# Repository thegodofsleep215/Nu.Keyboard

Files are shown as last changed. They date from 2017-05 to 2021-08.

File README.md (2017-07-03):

# Overview
The purpose of this repo is to document and provide my experience in making a mechanical keyboard. Why I made my own instead of using someone elses. The layout of the keys, the parts I used. How to wire a keyboard. And last but not least, how to program the firmware.

1. [Motivations](Motivation/README.md)
2. [Keyboard Layout](Layout/README.md)
3. [Parts](Parts/README.md)
4. [Wiring](Wiring/README.md)
5. [Firmware Programming](Firmware/README.md)

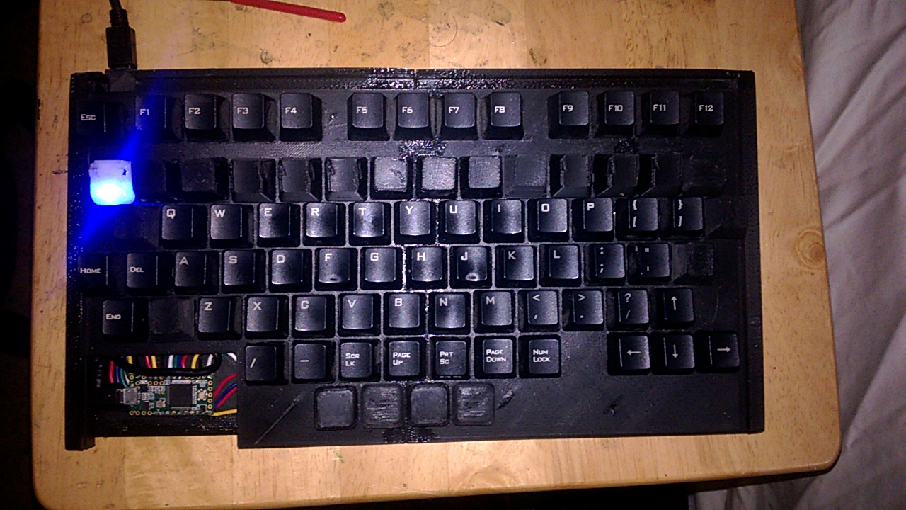
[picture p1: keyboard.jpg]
Mostly Finished Keyboard


# References
Some of the reference I used.
## General
* http://pcbheaven.com/wikipages/How_Key_Matrices_Works/
* http://blog.komar.be/how-to-make-a-keyboard-the-matrix/
## Keyboard Layout
* https://geekhack.org/index.php?topic=47744.0
* https://upload.wikimedia.org/wikipedia/commons/1/10/Key_offset_in_alphanumeric_section_of_a_keyboard_according_to_DIN_2137-2--2012-06.svg
## Wiring
* https://deskthority.net/workshop-f7/brownfox-step-by-step-t6050.html
## Programming
* https://github.com/tmk/tmk_keyboard

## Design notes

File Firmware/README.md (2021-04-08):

# Firmware
## Disclaimer 
There may be more efficient ways of solving this problem. This worked for me to the point where I can't tell the difference between it and a manufactured keyboard.

## Looping
The program runs in a loop. Executing what I am assuming is as fast as the controller can go. On every loop your program will need to read which rows/columns have been pressed or depressed and then send the information on to the computer.

## I/O Types
It is important to understand the I/O types for pins. Since you wire a keyboard in a matrix and read rows and columns. Your firmware will need to switch pins constantly to ensure it is reading the correct value. The two input types are INPUT_PULLDOWN, and INPUT_PULLUP. The first is LOW when the switch is open and HIGH when the switch is closed. The other is the opposite. You'll also need to set the output of your other pin correctly. When using INPUT_PULLDOWN set your other pin mode to OUTPUT and write HIGH to it. When reading from an INPUT_PULLUP pin you'll need to set the other pin's mode to OUTPUT_OPENDRAIN and write LOW to it.

## Selecting Row and Columns 
This program tests each button individually. It iterates over each row for each column. It selects a column (minding I/O types talked about above) and reads from it. It then does the same for every row. Each time a row is read the program tests to see is a key has been pressed or depressed, saving the state to a buffer. After all columns and rows have been read key modifiers are set (ctrl, alt, gui...), LEDs are toggled, and the information is sent along to the computer.

Some simplified pseudo-code:
* Select Column
  * Read Column
  * Deselect Column
  * Select Row
    * Read Row
    * Toggle Press/Depress as needed
    * Deselct Row
* Set Modifiers
* Toggle LEDs
* Send to Computer

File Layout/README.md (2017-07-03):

# Layout
## Mostly Standard
I'm not interested anything drastic like dvorak. The main section of the keybaord was to remain mostly intact. The section with the arrows keys and over would be lopped off and consolidated with the main keyboard.
## The Spacebar
As the main driver was to add more buttons for the thumb the spacebar would only be one [unit](https://deskthority.net/wiki/Unit). In it's place from left to right would be the windows key, tab, spacebar, alt, backspace, delete, and context menu. This row was going to be aligened with the one above it.
## Another Row
It seemed reasonable to add another row below the space bar. This is a four button row offset half a unit from the spacebar row. From left to right it would have page up, shift, control, page down.
## Arrow Keys
I like using the arrow key for some things. I moved that left under the enter key.
## Other Modifications
Since some of the keys haved moved under the thumb. I filled in some missing keys around. Tilde got moved to where Tab was, caps lock moved to where tilde was, backslash got moved to where caps lock was, insert home and end went on the left side filling out where shift and part of caps lock were. Last I put print sreen where backspace was and Pause/Break where backslash was. Believe it or not I use Pause/Break.

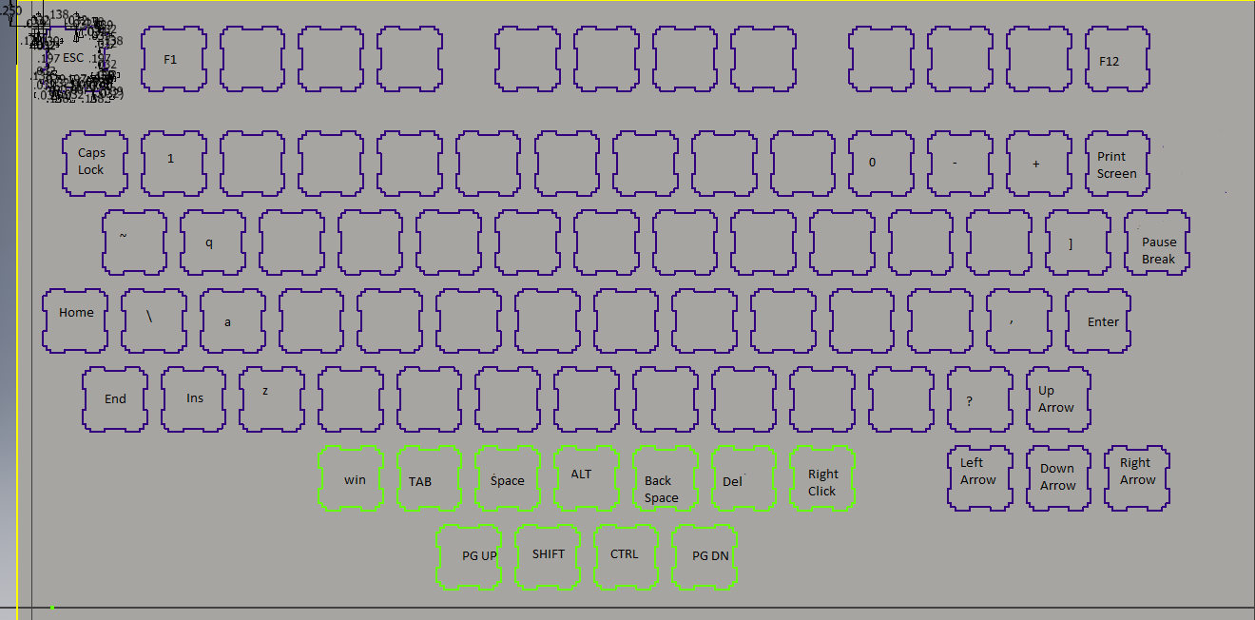
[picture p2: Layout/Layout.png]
Rough Layout of the kaycap placment.


# Key Caps
## Parametric Key Caps and Unconventional Key Locations
I primarily use a 'DAS Keyboard' which has parametric keycaps. I though I'd play with this a bit since I put some keys in unconventional locations. My new row has a very short key cap new row to make it easier to avoid fat finger it. I'd also make caps lock and print screen shorter than the keys around them for the same reason. The spacebar row also got keys angled for the number row, since I didn't want my fingers to hit them as easily.

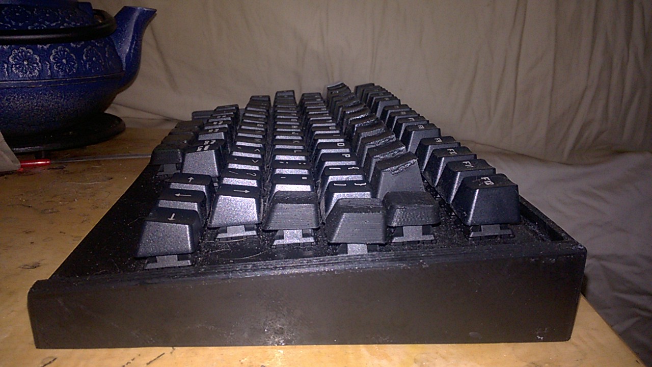
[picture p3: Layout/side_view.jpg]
Side view of key caps.


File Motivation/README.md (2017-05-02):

# Motivation
## Left Handed Gaming Options
As a lefty I use IJLK instead of WASD for gaming. There are more buttons for the pinky on right side of the keyboard. As I used them more and more I started to get a strain injury in my forearm. Instead of doing the sensible thing of remapping keys to use my pinky less. I stared at the space bar in disgust. I use my thumb a lot when I use a controller, why not when on a keyboard? The original idea was not to make a keyboard, but instead a gaming a device that had enough keys for one had to reach without moving. Somthing like the 'Razer Nostromo,' with no stick and more buttons.
## Programmer
As I started to lay out the design it occurred to me it would be simple enough to mirror what I what I had to make a keyboard. I'd only put the keys I used and lop off the number pad to make it nice and compact. Since I'm going for a "don't move your hand" approach for gaming why not for programming/typing as well. I use VIM or a VIM plug in for most all work, but that doesn't always exist. Since I'll be using my thumb more for gaming, why not when typing as well?
## Learning How
After I had a layout I liked I started to search around for tutorials. That's when I ran across the 'ErgoDox.' An ergnomical keybaord that had the same why-is-the-space-bar-so-big inspiration. As I already had the itch to do it myself I decided it would be best just to make my own. I've not really played with Arduinos and this seems like a great excuse. The project is both useful and educational!
## 3D Printer
I own a 3D printer. This helps justify my purchase...as if I needed to...
## This Document
It was not on my radar to create this document when I started. I wanted to make every aspect of my keyboard; key layout, case, wire it, and program it. There is a lot of good info on how to do the first three, but I was having trouble finding a good guide on how to program a keyboard. Everything I found pointed to, [tmk_keyboard](https://github.com/tmk/tmk_keyboard). A great resource, and if you don't want to write your own firmware I suggest using it. It was not for me though. So I was left to bashing my head and reading forums about teensyduino. So after all I went through I thought I'd write something for the next guy or gal. So if you are looking write your own keyboard firmware, then this doc was made for you. I hope it helps.

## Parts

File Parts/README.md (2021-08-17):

# Parts
<table>
  <tr><th>Type</th><th>Part Used</th><th>Quantity</th></tr>
  <tr><td>Switch</td><td>Cherry MX Brown</td><td>82</td></tr>
  <tr><td>Diodes</td><td>1N4148</td><td>82</td></tr>
  <tr><td>LED</td><td>Blue 3MM LED</td><td>1</td></tr>
  <tr><td>Resistor</td><td>Came with LED</td><td>1</td></tr>
  <tr><td>KeyCaps</td><td>Donor keys from DAS Keyboard, 3D prints from http://www.thingiverse.com/thing:468651</td><td>82</td></tr>
  <tr><td>Controller</td><td>Teensyduino 3.2</td><td>1</td></tr>
</table>

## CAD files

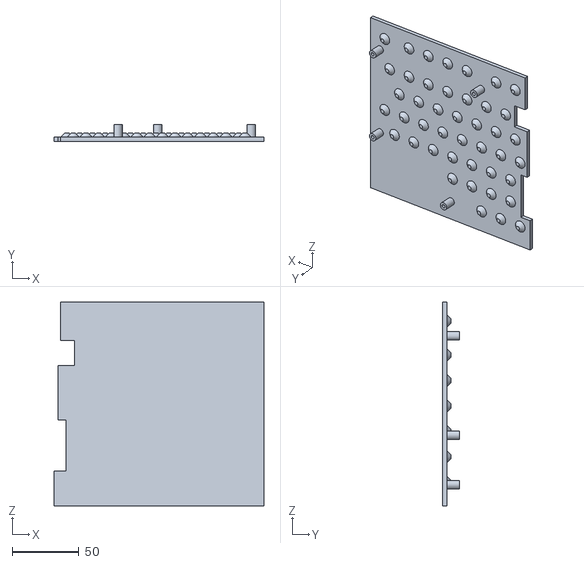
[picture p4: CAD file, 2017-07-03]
Parts/3D Models/bottom_left.stl
157.2 x 12.7 x 152.4

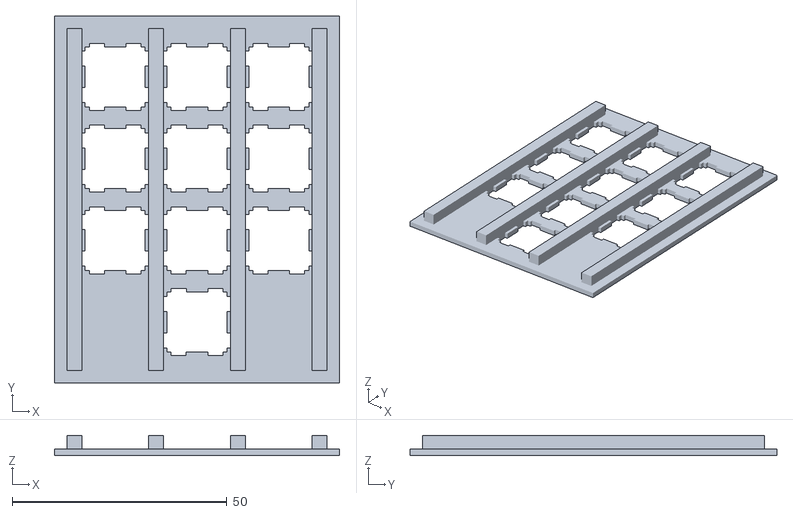
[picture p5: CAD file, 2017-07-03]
Parts/3D Models/number_pad_mount_plate.stl
66.4 x 85.4 x 4.67

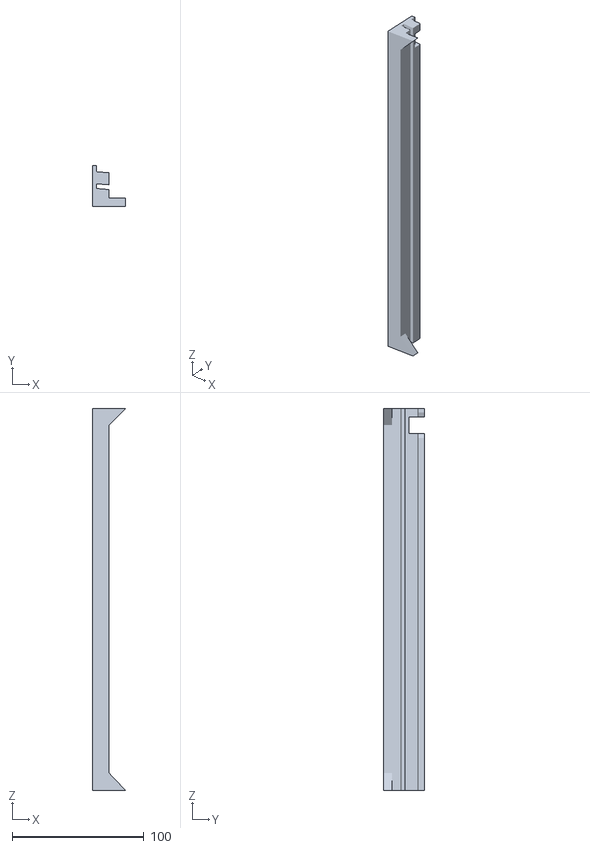
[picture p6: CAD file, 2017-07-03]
Parts/3D Models/back.stl
25.4 x 31.0 x 290.2

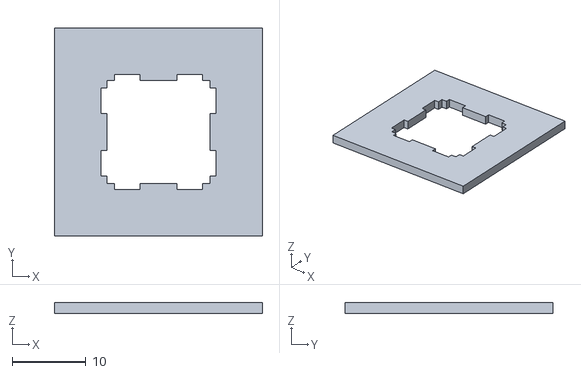
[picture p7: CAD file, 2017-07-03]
Parts/3D Models/demo_mount_plate.stl
28.3 x 28.3 x 1.50

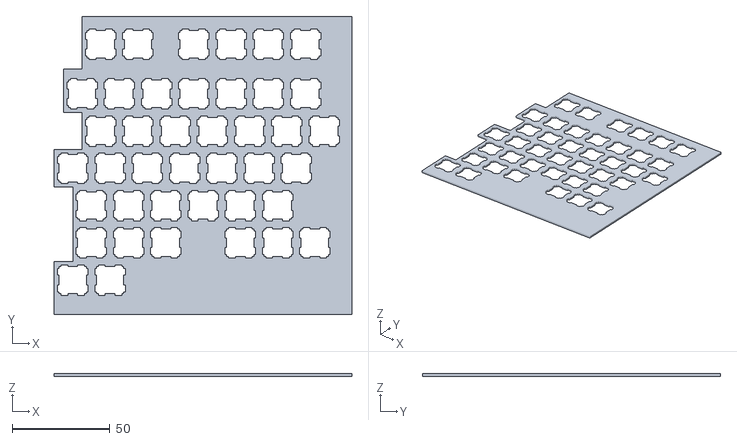
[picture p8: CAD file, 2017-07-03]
Parts/3D Models/switch_mount_plate_right.stl
152.3 x 152.4 x 1.50

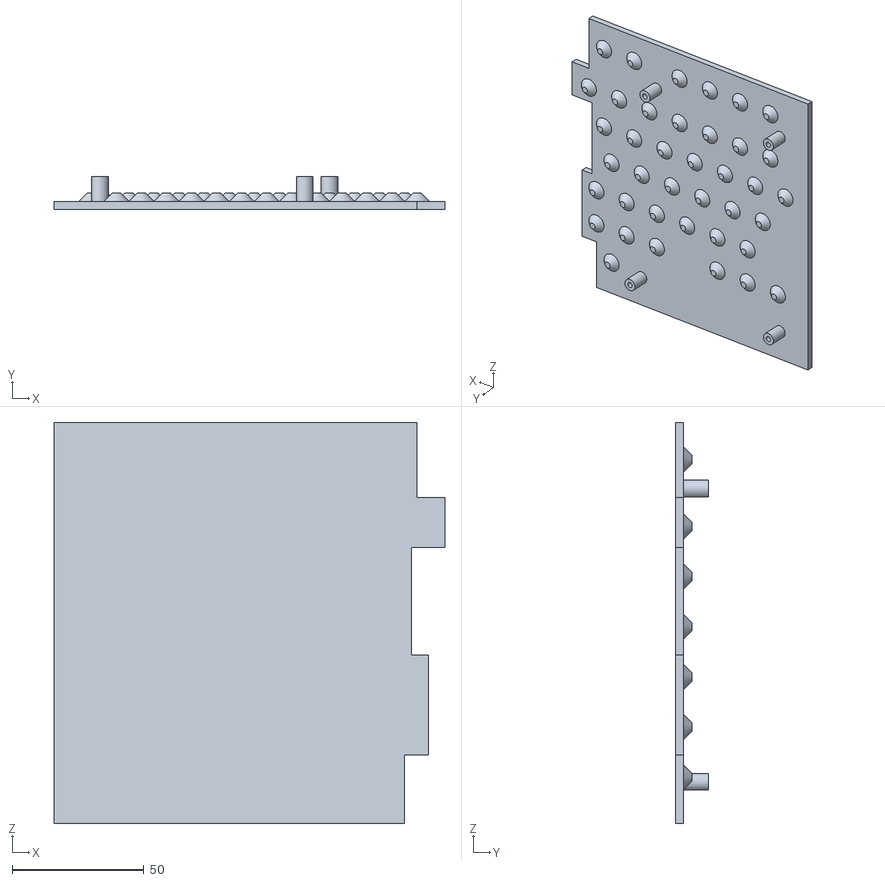
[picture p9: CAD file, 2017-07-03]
Parts/3D Models/bottom_right.stl
148.5 x 12.7 x 152.4

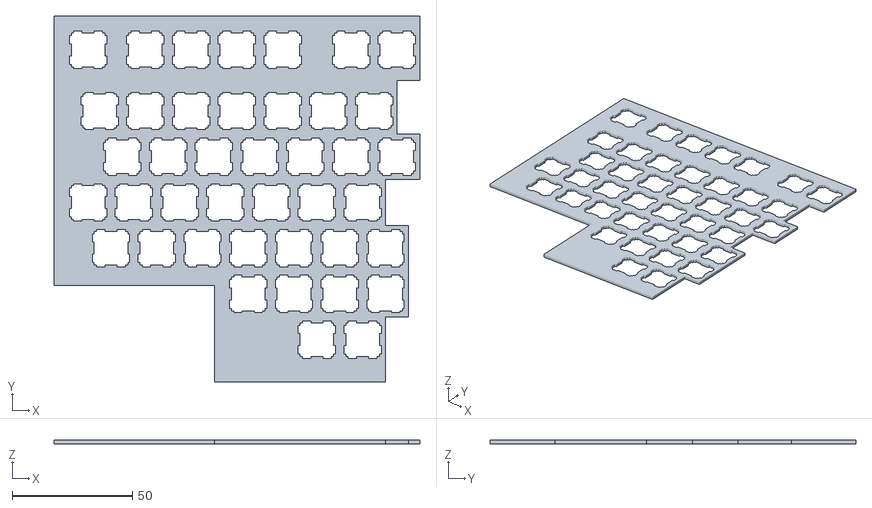
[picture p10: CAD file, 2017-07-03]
Parts/3D Models/switch_mount_plate_left.stl
152.2 x 152.4 x 1.50

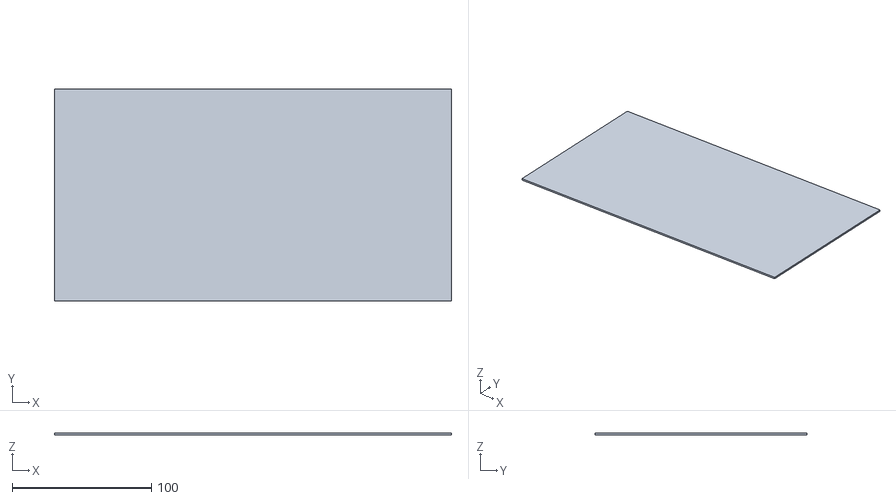
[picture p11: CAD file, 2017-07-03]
Parts/3D Models/switch_mount_plate.stl
285.5 x 152.4 x 1.50

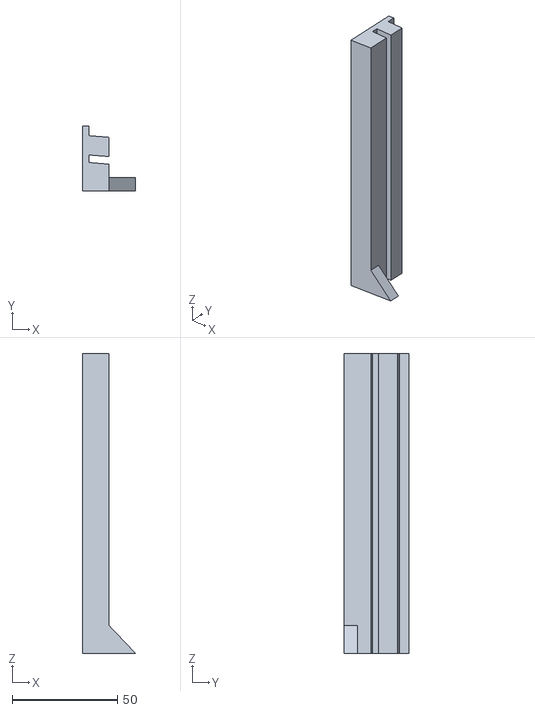
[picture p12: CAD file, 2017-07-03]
Parts/3D Models/back_right.stl
25.4 x 31.0 x 142.6

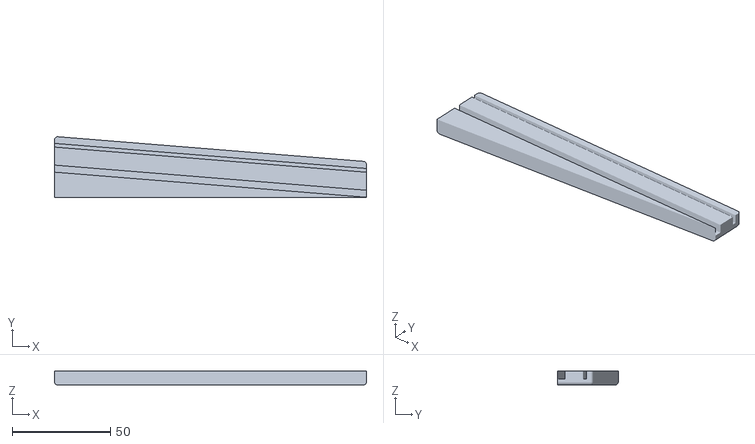
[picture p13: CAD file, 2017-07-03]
Parts/3D Models/wall.stl
158.8 x 30.8 x 7.14

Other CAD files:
Parts/3D Models/back_left.stl

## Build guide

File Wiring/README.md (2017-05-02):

# Wiring
I'm not going to go very indepth with this step. I've included the reference I used to learn this. They are very good and I don't see the point in duplicating that info. 
The bottom two rows were wired as a single row since they are 13 keys in total.

## Tips
* I used my diodes to wire the rows, wires for the columns. It doesn't matter, it just made it easier.
* Make sure all of your diodes go in the same direction.
* I found it easier to run the diodes/wires the length of the row/column and cut it, then soder a wire from a convenient location on the row/column and run the cable to the controller.
* If you want your rows and columns to line up to pin numbers in a left-to-right top-to-bottom way, remember that you are sodering something that is upside down.
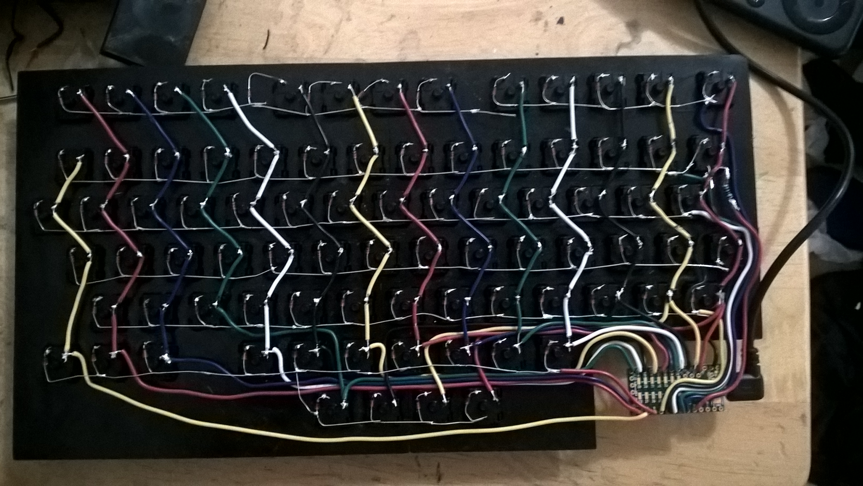
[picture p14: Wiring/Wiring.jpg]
Final Wiring Done


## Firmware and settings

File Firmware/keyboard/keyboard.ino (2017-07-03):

// Time to wait for key debounce
#define DEBOUNCE 1

// Number of columns on the keyboard matrix (highest if columns are not equal)
#define NUM_OF_COLS 14
// Number of rows on the keyboard matrix (highest if rows are not equal)
#define NUM_OF_ROWS 6

// Pin wired to caps lock LED. -1 if no LED is present.
#define CAPS_LOCK_PIN 3
// Pin wired to scroll lock LED. -1 if no LED is present.
#define SCROLL_LOCK_PIN -1
// Pin wired to num lock LED. -1 if no LED is present.
#define NUM_LOCK_PIN -1

// Pin numbers for columns in order they are wired with respect to keyMap. FYI: Column pins are INPUT_PULLDOWN
int cols[NUM_OF_COLS] =  {23,22,21,20,19,18,17,16,15,14,13,12,11,10};
// Pin numbers for rows in order they are wired with respect to keyMap. FYI: Row pins are INPUT_PULLUP
int rows[NUM_OF_ROWS] = {4,5,6,7,8,9};

// The order that buttons are wired. FYI, keyMap[0][0] will activated if pins at cols[0], rows[0] are on.
int keyMap[NUM_OF_ROWS][NUM_OF_COLS] = 
{
  { KEY_ESC,       KEY_F1,        KEY_F2, KEY_F3, KEY_F4, KEY_F5, KEY_F6, KEY_F7, KEY_F8, KEY_F9,    KEY_F10,    KEY_F11,        KEY_F12,         0 },
  { KEY_CAPS_LOCK, KEY_1,         KEY_2,  KEY_3,  KEY_4,  KEY_5,  KEY_6,  KEY_7,  KEY_8,  KEY_9,     KEY_0,      KEY_MINUS,      KEY_EQUAL,       KEY_PRINTSCREEN },
  { KEY_TILDE,     KEY_Q,         KEY_W,  KEY_E,  KEY_R,  KEY_T,  KEY_Y,  KEY_U,  KEY_I,  KEY_O,     KEY_P,      KEY_LEFT_BRACE, KEY_RIGHT_BRACE, KEY_PAUSE},
  { KEY_HOME,      KEY_BACKSLASH, KEY_A,  KEY_S,  KEY_D,  KEY_F,  KEY_G,  KEY_H,  KEY_J,  KEY_K,     KEY_L,      KEY_SEMICOLON,  KEY_QUOTE,       KEY_ENTER },
  { KEY_END,       KEY_INSERT,    KEY_Z,  KEY_X,  KEY_C,  KEY_V,  KEY_B,  KEY_N,  KEY_M,  KEY_COMMA, KEY_PERIOD, KEY_SLASH,      KEY_UP,          0 },
  { KEY_PAGE_UP, MODIFIERKEY_SHIFT, MODIFIERKEY_CTRL, MODIFIERKEY_GUI, KEY_TAB, KEY_SPACE, MODIFIERKEY_ALT, KEY_BACKSPACE, KEY_DELETE, 101, KEY_PAGE_DOWN, KEY_LEFT, KEY_DOWN, KEY_RIGHT }
};


// Blow this line is "unconfigurable"


// 2D array to keep track of which keys are pressed
int** keyState;

// Storage for which key is pressed in which "slot"
int keys[6] {0, 0, 0, 0, 0, 0};

// Storage for pressed modifiers.
int modifiers[4] {0, 0, 0, 0};
// Indexs for modifier keys in modifiers buffer
#define SHIFT 0
#define CTRL 1
#define ALT 2
#define GUI 3

// LED numbers for usb_keyboard.h
#define USB_LED_NUM_LOCK 0
#define USB_LED_CAPS_LOCK 1
#define USB_LED_SCROLL_LOCK 2
#define USB_LED_COMPOSE 3
#define USB_LED_KANA 4

void setup() {
  // Turn on LEDs for output
  if(CAPS_LOCK_PIN >= 0)
  {
    pinMode(CAPS_LOCK_PIN, OUTPUT);
  }
  if(SCROLL_LOCK_PIN >= 0)
  {
    pinMode(SCROLL_LOCK_PIN, OUTPUT);
  }
  if(NUM_LOCK_PIN >= 0)
  {
    pinMode(NUM_LOCK_PIN, OUTPUT);
  }


  // Create and initialize keyState off rows by columns.
  keyState = (int**)malloc(NUM_OF_ROWS * sizeof(int*)); 
  for (int i = 0; i < NUM_OF_ROWS; i++) {
       keyState[i] = (int *)malloc(NUM_OF_COLS * sizeof(int));
  }
  for (int i = 0; i < NUM_OF_ROWS; i++) {
    for(int c = 0; c < NUM_OF_COLS; c++)
    {
      keyState[i][c] = LOW;
    }
  }
  
}

// Read the column, HIGH if on LOW of off.
int ReadColumn(int index)
{
  for(int i = 0; i < NUM_OF_ROWS; i++)
  {
    pinMode(rows[i], OUTPUT);
    digitalWrite(rows[i], HIGH);
  }
  pinMode(cols[index], INPUT_PULLDOWN);
  delay(DEBOUNCE);
  return digitalRead(cols[index]);
}

// Checks for an open button to send
int CheckForButton()
{
    for(int i = 0; i < 6; i++){
      if(keys[i] == 0) return i;
    }
    return -1;
}

// Sets the modifier buffer if a modifier key was pressed.
bool SetModifier(int b)
{
  if(b == MODIFIERKEY_SHIFT)
  {
    modifiers[SHIFT] = MODIFIERKEY_SHIFT;
    return true;
  }
  else if (b == MODIFIERKEY_CTRL)
  {
    modifiers[CTRL] = MODIFIERKEY_CTRL;
    return true;
  }
  else if (b == MODIFIERKEY_ALT)
  {
    modifiers[ALT] = MODIFIERKEY_ALT;
    return true;
  }
  else if (b == MODIFIERKEY_GUI)
  {
    modifiers[GUI] = MODIFIERKEY_GUI;
    return true;
  }
  return false;
}

// Unsets a modifer button from the buffer.
bool UnsetModifier(int b)
{
    if(b == MODIFIERKEY_SHIFT)
  {
    modifiers[SHIFT] = 0;
    return true;
  }
  else if (b == MODIFIERKEY_CTRL)
  {
    modifiers[CTRL] = 0;
    return true;
  }
  else if (b == MODIFIERKEY_ALT)
  {
    modifiers[ALT] = 0;
    return true;
  }
  else if (b == MODIFIERKEY_GUI)
  {
    modifiers[GUI] = 0;
    return true;
  }
  return false;
}

// Ors all modifiers and sets them on the keyboard.
void SendModifiers()
{
  int m = 0;
  for(int i = 0; i < 4; i++)
  {
    m |= modifiers[i];
  }
  Keyboard.set_modifier(m);
}

// Checks to see if a button is pressed in the buffer
int CheckForPressedButton(int b)
{
  for(int i = 0; i < 6; i++){
    if(keys[i] == b)
    { 
      return i;
    }
  }
  return -1;
}

// Sets the key based off of the position in the buffer
void PressButton(int index, int b){
  keys[index] = b;
    switch(index + 1){
      case 1:
        Keyboard.set_key1(b);
        break;
      case 2:
        Keyboard.set_key2(b);
        break;
      case 3:
        Keyboard.set_key3(b);
        break;
      case 4:
        Keyboard.set_key4(b);
        break;
      case 5:
        Keyboard.set_key5(b);
        break;
      case 6:
        Keyboard.set_key6(b);
        break;
    
  }
}

// Unpresses a key based off of its position in the buffer
void DepressButton(int index){
  keys[index] = 0;
  switch(index + 1){
    case 1:
      Keyboard.set_key1(0);
      break;
    case 2:
      Keyboard.set_key2(0);
      break;
    case 3:
      Keyboard.set_key3(0);
      break;
    case 4:
      Keyboard.set_key4(0);
      break;
    case 5:
      Keyboard.set_key5(0);
      break;
    case 6:
      Keyboard.set_key6(0);
      break;
  }
}

// Checks to see if LED lights should be on or off.
void ToggleLeds()
{
  if(CAPS_LOCK_PIN >= 0 && keyboard_leds & (1<<USB_LED_CAPS_LOCK))
  {
    digitalWrite(CAPS_LOCK_PIN, HIGH);
  }
  else
  {
    digitalWrite(CAPS_LOCK_PIN, LOW);
  }
  
  if(NUM_LOCK_PIN >= 0 && keyboard_leds & (1<<USB_LED_NUM_LOCK))
  {
    digitalWrite(NUM_LOCK_PIN, HIGH);
  }
  else
  {
    digitalWrite(NUM_LOCK_PIN, LOW);
  }
  
  if(SCROLL_LOCK_PIN >= 0 && keyboard_leds & (1<<USB_LED_NUM_LOCK))
  {
    digitalWrite(SCROLL_LOCK_PIN, HIGH);
  }
  else
  {
    digitalWrite(SCROLL_LOCK_PIN, LOW);
  }
}

// Test a key to see if it was just depressed.
void TryKeyDepressed(int r, int c, int readRow)
{
  if(readRow == HIGH && keyState[r][c] == HIGH)
  {
    keyState[r][c] = LOW;
    if(!UnsetModifier(keyMap[r][c]))
    {
      int b = CheckForPressedButton(keyMap[r][c]);
      if(b >= 0)
      {
        //digitalWrite(ledPin,LOW); 
        DepressButton(b);
      }
    }
  }
}

// Test a key to see if it was just pressed.
bool TryKeyPressed(int r, int c, int readRow)
{
  if(readRow == LOW && keyState[r][c] == LOW)
  {
    keyState[r][c] = HIGH;
    if(!SetModifier(keyMap[r][c]))
    {
      int b = CheckForButton();
      if(b >= 0)
      {
        //digitalWrite(ledPin,HIGH); 
        PressButton(b, keyMap[r][c]);
      }
    }
    return true;
  }
  return false;
}

void loop() {
  for(int c = 0; c < NUM_OF_COLS; c++)
  {
    int readC = ReadColumn(c);

    // Turn column read off
    pinMode(cols[c], OUTPUT_OPENDRAIN);
    digitalWrite(cols[c], LOW);
    delay(DEBOUNCE);
    
    for(int r = 0; r < NUM_OF_ROWS; r++)
    {
      // Turn on row for reading
      pinMode(rows[r], INPUT_PULLUP);
      
      int readRow = digitalRead(rows[r]);
      if(readC == HIGH)
      {
        if(!TryKeyPressed(r, c, readRow))
        {
          TryKeyDepressed(r, c, readRow);
        }
      }
      else
      {
        TryKeyDepressed(r, c, readRow);
      }
      // Turn row read off.
      pinMode(rows[r], OUTPUT);
      digitalWrite(rows[r], HIGH);
    }
    // Turn column write off.
    pinMode(cols[c], INPUT_PULLDOWN);
  }

  SendModifiers();
  ToggleLeds();
  Keyboard.send_now();
}

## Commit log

2017-05-02 Adding wiring.jpg
2017-07-03 Adding .stl files.
    [back.stl, back_left.stl, back_right.stl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]
